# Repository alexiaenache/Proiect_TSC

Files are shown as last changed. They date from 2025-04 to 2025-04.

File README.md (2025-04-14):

# 📖 OpenBook – E-Reader cu ESP32-C6

**-TSC-**  
Alexia-Ioana Enache – 331CA

---

## 🧠 Arhitectură generală

Sistemul reprezintă un cititor digital inteligent, construit în jurul microcontrollerului **ESP32-C6**, optimizat pentru consum redus și interacțiune minimă din partea utilizatorului, având ca scop principal afișarea eficientă de conținut pe un ecran E-Ink.

---

## 🧩 Componente principale și funcționalitate

### 1. ESP32-C6 – Unitatea centrală de control
- **Funcție:** Coordonează toate componentele, gestionează afișajul și comunicația.
- **Caracteristici cheie:**
  - Procesor RISC-V performant.
  - Suport Wi-Fi 6 (802.11ax) pentru actualizări sau funcționalitate în rețea.
  - Moduri avansate de economisire a energiei (deep sleep, modem sleep).

---

### 2. Afișaj E-Ink
- **Tip:** Ecran monocrom (ex. 2.9"), optimizat pentru citire.
- **Control:** Prin interfață SPI, cu linii dedicate de comandă (CS, DC, RST, BUSY).
- **Beneficii:** Consum de curent extrem de redus între refresh-uri – ideal pentru aplicații de tip e-paper.

---

### 3. Senzor de mediu – BME688
- **Scop:** Monitorizare temperatură, umiditate, presiune și calitatea aerului.
- **Conectivitate:** I2C (implicit) sau SPI (alternativ).
- **Consum:** µA în stand-by, câțiva mA în funcționare activă.

---

### 4. Ceas în timp real – DS3231
- **Funcționalitate:** Menține ora exactă, ideal pentru time-stamping sau notificări programate.
- **Interfață:** I2C + pin de alarmă (INT/SQW).
- **Consum:** Sub 2 µA în menținerea ceasului pe baterie.

---

### 5. Memorie SPI – W25Q512 (64Mbit NOR Flash)
- **Rol:** Depozitare pentru fișiere, cărți, date configurabile.
- **Protocol:** SPI, suportând frecvențe mari pentru transfer rapid.
- **Eficiență energetică:** Consumă doar în timpul operațiunilor active.

---

### 6. Sistem de alimentare
- **USB-C:** Intrare de 5V pentru alimentare și comunicație.
- **Încărcare baterie:** MCP73831 controlează încărcarea Li-Po, cu curent reglat prin rezistor (ex. 500mA).
- **Conversie tensiune:**
  - **LDO / DC-DC:** Reglează 3.7V de la baterie la 3.3V pentru întreaga platformă.
  - Opțional: step-up DC-DC pentru a obține 5V dacă e necesar.

---

### 7. Control fizic – Butoane SMD
- 3 butoane dedicate: Boot, Reset și Funcțional.
- Legate la GPIO-uri configurate cu pull-up/pull-down.
- Logica de debounce poate fi software sau hardware.

---

### 8. Alte funcționalități
- Protecții ESD aplicate pe liniile critice: USB, SPI, I2C, alimentare.
- **Test Pads**: Acces facil la semnale importante (MISO, MOSI, SCK, RX, TX, GND, 3V3) pentru depanare sau programare externă.

---

## 🛠️ Considerații hardware (PCB Design)

### Rutare & alimentare:
- **Trasee de putere:** Minim 0.3 mm pentru 3V3, 5V, VBAT.
- **Linii de semnal:** Minim 0.15 mm pentru SPI, I2C, UART etc.
- **Grosime PCB:** Ideal < 1 mm pentru carcase compacte.

### Decuplare & stabilitate:
- Condensatoare **100nF** (0402) pentru fiecare pin VCC.
- Condensatoare **4.7 µF - 10 µF** pentru stabilizarea LDO și surse locale.

### Antenă ESP32-C6:
- Zona antenei trebuie eliberată de cupru (decupaj în GND + semnale), conform datasheetului Espressif.

### DRC/ ERC:
- Verificări obligatorii:
  - Unghiuri ≤ 45°.
  - Planuri GND corect cusute cu via stitching.
  - Clearance și distanțe respectate conform producătorului.

### Layout:
- Componente doar pe **Top Layer** (SMD).
- USB-C și butoanele poziționate ergonomic și accesibil.

### Test Pad-uri:
- Expunere pentru debug, programare și validare semnale: 3V3, GND, RX, TX, SPI.

---
## 📐 Diagrama bloc

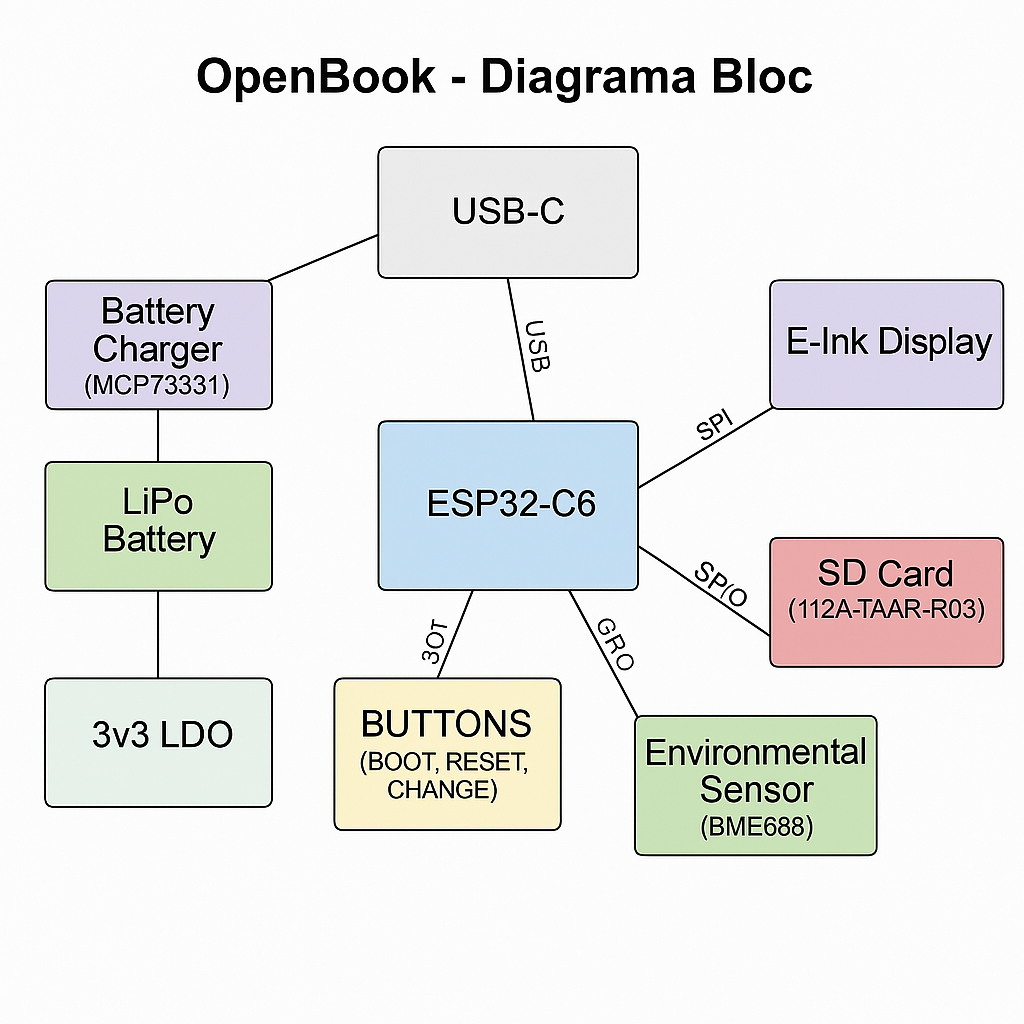
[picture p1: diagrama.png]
Diagrama Bloc


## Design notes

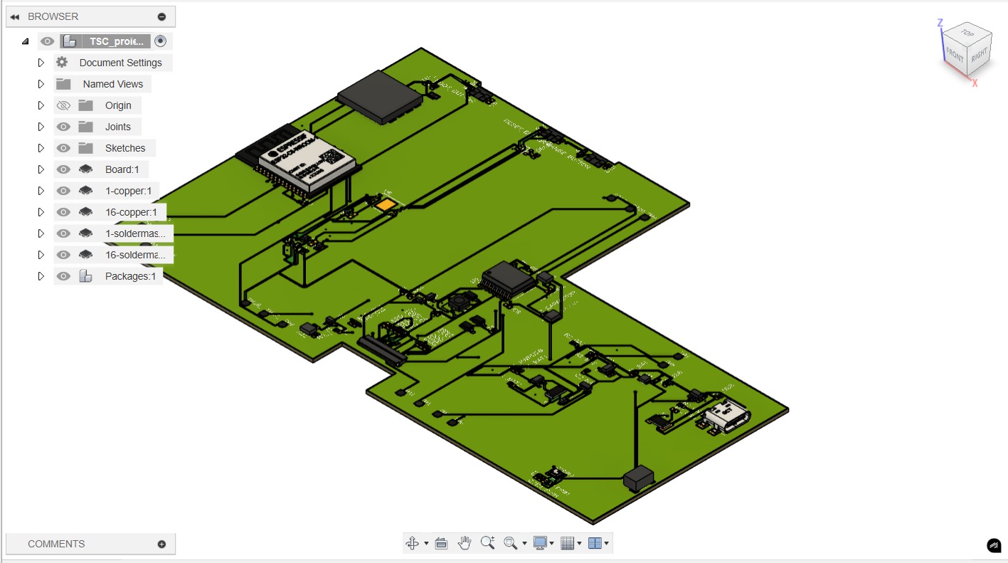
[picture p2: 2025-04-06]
Images/placa.jpeg

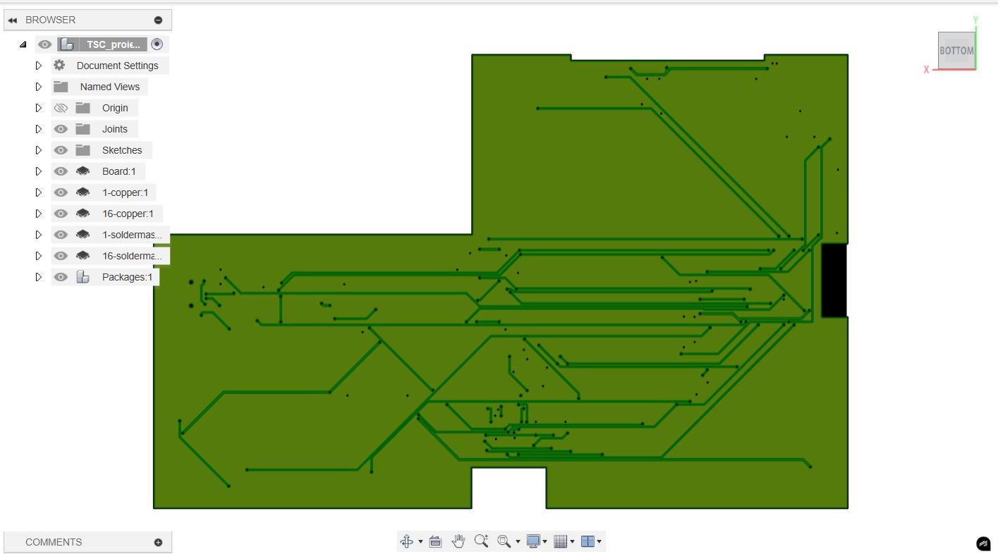
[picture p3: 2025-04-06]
Images/placa2.jpeg

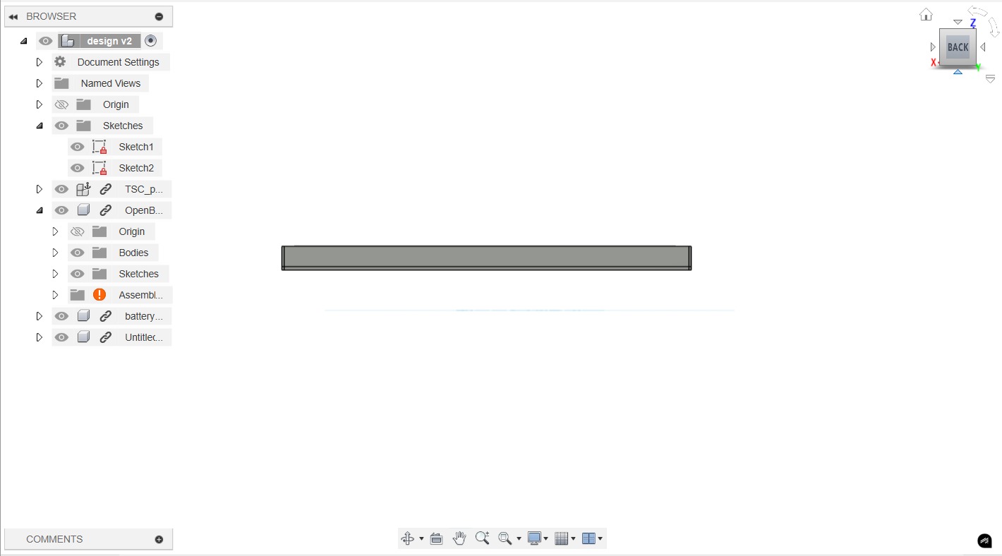
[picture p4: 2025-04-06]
Images/image.jpeg

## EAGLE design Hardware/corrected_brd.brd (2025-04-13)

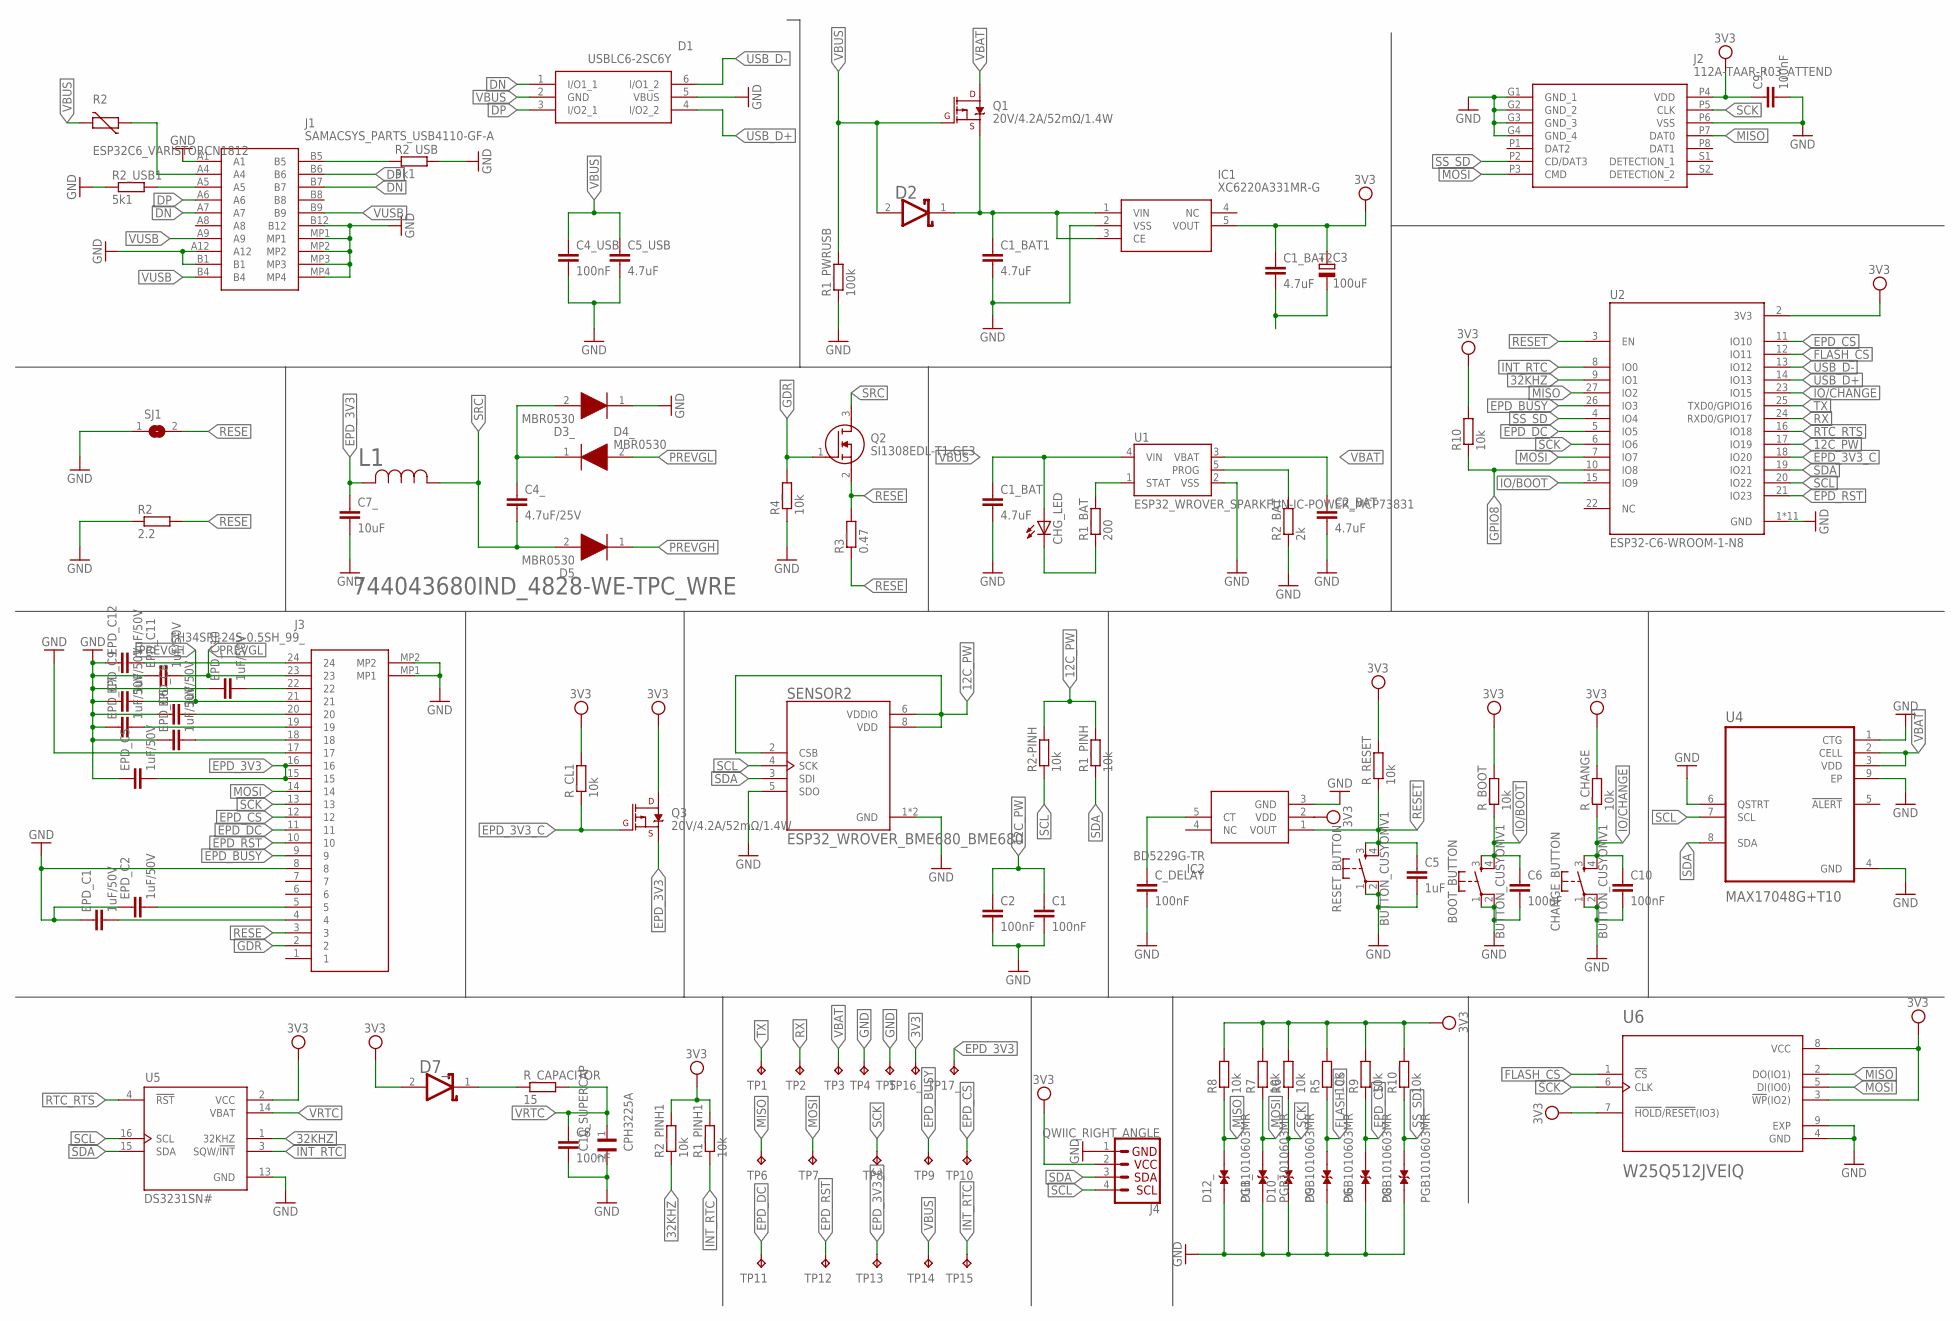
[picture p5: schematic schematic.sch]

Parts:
BOOT_BUTTON: BUTTON_CUSYOMV1; MYBUTTON
C1, C2, C4_USB, C8: 100nF; EAGLE-LTSPICE_C0402
C1_BAT, C1_BAT1, C1_BAT2, C2_BAT, C5_USB: 4.7uF; EAGLE-LTSPICE_C0402
C3: 100uF; RCL_CT3528
C4_: 4.7uF/25V; EAGLE-LTSPICE_C0402
C5: 1uF; EAGLE-LTSPICE_C0402
C6, C9_, C10: 100nF; ESP32_WROVER_EAGLE-LTSPICE_C0402
C7_: 10uF; EAGLE-LTSPICE_C0402
C10_SUPERCAP: CPH3225A; CAPCP3225X100N
CHANGE_BUTTON: BUTTON_CUSYOMV1; MYBUTTON
CHG_LED: ADAFRUIT_LEDCHIP-LED0603; ADAFRUIT_CHIP-LED0603
C_DELAY: 100nF; EAGLE-LTSPICE_C0402
D1: USBLC6-2SC6Y; SOT95P280X145-6N
D2, D7_: ESP32_WROVER_AVX---SD0805S020S1R0_AVX_SD0805S020S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; ESP32_WROVER_AVX---SD0805S020S1R0_AVX_SD0805S020S1R0_0
D3_, D4_, D5: MBR0530; SOD3716X135N
D6, D8, D9, D10_, D11_, D12_: PGB1010603MR; DIOC1608X36N
EPD_C1, EPD_C2, EPD_C5, EPD_C6, EPD_C7, EPD_C8, EPD_C9, EPD_C10, EPD_C11, EPD_C12: 1uF/50V; EAGLE-LTSPICE_C0402
IC1: XC6220A331MR-G; SOT95P280X120-5N
IC2: BD5229G-TR; SOT95P280X125-5N
J1: SAMACSYS_PARTS_USB4110-GF-A; SAMACSYS_PARTS_USB4110GFA
J2: 112A-TAAR-R03_ATTEND; 112ATAARR03ATTEND
J3: FH34SRJ-24S-0.5SH_99_; FH34SRJ24S05SH99
J4: QWIIC_RIGHT_ANGLE; JST04_1MM_RA
L1: 744043680IND_4828-WE-TPC_WRE; IND_4828-WE-TPC_WRE
Q1, Q3: 20V/4.2A/52mΩ/1.4W; ESP32_WROVER_SPARKFUN-DISCRETESEMI_SOT23-3
Q2: SI1308EDL-T1-GE3; SOT65P210X110-3N
R1_BAT: 200; ESP32_WROVER_EAGLE-LTSPICE_R0402
R1_PINH, R1_PINH1, R2-PINH, R2_PINH1, R4_, R5, R6, R7, R8, R9, R10, R10_: 10k; ESP32_WROVER_EAGLE-LTSPICE_R0402
R1_PWRUSB: 100k; ESP32_WROVER_EAGLE-LTSPICE_R0402
R2: ESP32C6_VARISTORCN1812; ESP32C6_VARISTOR_CT/CN1812
R2_: 2.2; ESP32_WROVER_EAGLE-LTSPICE_R0402
R2_BAT: 2k; ESP32_WROVER_EAGLE-LTSPICE_R0402
R2_USB, R2_USB1: 5k1; ESP32_WROVER_EAGLE-LTSPICE_R0402
R3_: 0.47; ESP32_WROVER_EAGLE-LTSPICE_R0402
RESET_BUTTON: BUTTON_CUSYOMV1; MYBUTTON
R_BOOT: 10k; ESP32_WROVER_EAGLE-LTSPICE_R0402
R_CAPACITOR: 15; ESP32_WROVER_EAGLE-LTSPICE_R0402
R_CHANGE: 10k; ESP32_WROVER_EAGLE-LTSPICE_R0402
R_CL1: 10k; ESP32_WROVER_EAGLE-LTSPICE_R0402
R_RESET: 10k; ESP32_WROVER_EAGLE-LTSPICE_R0402
SENSOR2: ESP32_WROVER_BME680_BME680; ESP32_WROVER_BME680_PSON80P300X300X100-8N
SJ1: SJ
TP1, TP2, TP3, TP4, TP5, TP6, TP7, TP8, TP9, TP10, TP11, TP12, TP13, TP14, TP15, TP16_, TP17_: TPTP20R; TP20R
U1: ESP32_WROVER_SPARKFUN-IC-POWER_MCP73831; ESP32_WROVER_SPARKFUN-IC-POWER_SOT23-5
U2: ESP32-C6-WROOM-1-N8; XCVR_ESP32-C6-WROOM-1-N8
U4: MAX17048G+T10; SON50P200X200X80-9N
U5: DS3231SN#; SOIC127P1032X265-16N
U6: W25Q512JVEIQ; SON127P600X800X80-9N

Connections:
3V3: C1_BAT2.1, C3.+, C9_.1, D7_.2 (ANODE), IC1.5 (VOUT), IC2.2 (VDD), J2.P4 (VDD), J4.2, Q3.3 (D), R1_PINH1.2, R2_PINH1.2, R5.2, R6.2, R7.2, R8.2, R9.2, R10.2, R10_.2, R_BOOT.2, R_CHANGE.2, R_CL1.2, R_RESET.2, TP16_.TP, U2.2 (3V3), U5.2 (VCC), U6.3 (!WP!(IO2)), U6.7 (!HOLD!/!RESET!(IO3)), U6.8 (VCC)
12C_PW: C1.1, C2.1, R1_PINH.2, R2-PINH.2, SENSOR2.2 (CSB), SENSOR2.6 (VDDIO), SENSOR2.8 (VDD), U2.17 (IO19)
32KHZ: R2_PINH1.1, U2.9 (IO1), U5.1 (32KHZ)
DN: D1.1 (I/O1_1), J1.A7, J1.B7
DP: D1.3 (I/O2_1), J1.A6, J1.B6
EPD_3V3: C7_.1, EPD_C5.2, J3.15, J3.16, L1.2, Q3.2 (S), TP17_.TP
EPD_3V3_C: Q3.1 (G), R_CL1.1, TP13.TP, U2.18 (IO20)
EPD_BUSY: J3.9, TP9.TP, U2.26 (IO3)
EPD_CS: D6.2, J3.12, R9.1, TP10.TP, U2.11 (IO10)
EPD_DC: J3.11, TP11.TP, U2.5 (IO5)
EPD_RST: J3.10, TP12.TP, U2.21 (IO23)
FLASH_CS: D9.2, R5.1, U2.12 (IO11), U6.1 (!CS)
GDR: J3.2, Q2.1 (G), R4_.2
GND: BOOT_BUTTON.1, BOOT_BUTTON.2, C1.2, C1_BAT.2, C1_BAT1.2, C2.2, C2_BAT.2, C4_USB.2, C5.2, C5_USB.2, C6.2, C7_.2, C8.2, C9_.2, C10.2, C10_SUPERCAP.2, CHANGE_BUTTON.1, CHANGE_BUTTON.2, C_DELAY.2, D1.5 (VBUS), D3_.1 (K), D6.1, D8.1, D9.1, D10_.1, D11_.1, D12_.1, EPD_C1.1, EPD_C2.1, EPD_C5.1, EPD_C6.1, EPD_C7.1, EPD_C8.1, EPD_C9.1, EPD_C10.1, EPD_C11.1, EPD_C12.1, IC1.2 (VSS), IC2.3 (GND), J1.A1, J1.A12, J1.B1, J1.B12, J1.MP1, J1.MP2, J1.MP3, J1.MP4, J2.G1 (GND_1), J2.G2 (GND_2), J2.G3 (GND_3), J2.G4 (GND_4), J2.P6 (VSS), J3.8, J3.17, J3.MP1, J3.MP2, J4.1, R1_PWRUSB.1, R2_.1, R2_BAT.1, R2_USB.2, R2_USB1.1, R4_.1, RESET_BUTTON.1, RESET_BUTTON.2, SENSOR2.1 (GND), SENSOR2.5 (SDO), SENSOR2.7 (GND), SJ1.1, TP4.TP, TP5.TP, U1.2 (VSS), U2.1 (GND), U2.28 (GND), U2.29_1 (GND), U2.29_2 (GND), U2.29_3 (GND), U2.29_4 (GND), U2.29_5 (GND), U2.29_6 (GND), U2.29_7 (GND), U2.29_8 (GND), U2.29_9 (GND), U4.1 (CTG), U4.4 (GND), U4.6 (QSTRT), U4.9 (EP), U5.13 (GND), U6.4 (GND), U6.9 (EXP)
GPIO8: R10.1, U2.10 (IO8)
INT_RTC: R1_PINH1.1, TP15.TP, U2.8 (IO0), U5.3 (SQW/!INT)
IO/BOOT: BOOT_BUTTON.3, BOOT_BUTTON.4, C6.1, R_BOOT.1, U2.15 (IO9)
IO/CHANGE: C10.1, CHANGE_BUTTON.3, CHANGE_BUTTON.4, R_CHANGE.1, U2.23 (IO15)
MISO: D12_.2, J2.P7 (DAT0), R8.1, TP6.TP, U2.27 (IO2), U6.2 (DO(IO1))
MOSI: D11_.2, J2.P3 (CMD), J3.14, R7.1, TP7.TP, U2.7 (IO7), U6.5 (DI(IO0))
unnamed: J1.A4, R2.1
unnamed: J1.A5, R2_USB1.2
unnamed: J1.B5, R2_USB.1
unnamed: C1_BAT1.1, D2.1 (CATHODE), IC1.1 (VIN), IC1.3 (CE), Q1.2 (S)
unnamed: C4_.1, D3_.2 (A), D4_.1 (K)
unnamed: C1_BAT2.2, C3.-
unnamed: EPD_C12.2, J3.24
unnamed: EPD_C1.2, J3.4
unnamed: C_DELAY.1, IC2.5 (CT)
unnamed: R2_BAT.2, U1.5 (PROG)
unnamed: EPD_C2.2, J3.5
unnamed: EPD_C10.2, J3.22
unnamed: D7_.1 (CATHODE), R_CAPACITOR.1
unnamed: R1_BAT.2, U1.1 (STAT)
unnamed: CHG_LED.C, R1_BAT.1
unnamed: EPD_C8.2, J3.20
unnamed: EPD_C7.2, J3.19
unnamed: EPD_C6.2, J3.18
PREVGH: D5.1 (K), EPD_C9.2, J3.21
PREVGL: D4_.2 (A), EPD_C11.2, J3.23
RESE: J3.3, Q2.2 (S), R2_.2, R3_.1, R3_.2, SJ1.2
RESET: C5.1, IC2.1 (VOUT), RESET_BUTTON.3, RESET_BUTTON.4, R_RESET.1, U2.3 (EN)
RTC_RTS: U2.16 (IO18), U5.4 (!RST)
RX: TP2.TP, U2.24 (RXD0/GPIO17)
SCK: D10_.2, J2.P5 (CLK), J3.13, R6.1, TP8.TP, U2.6 (IO6), U6.6 (CLK)
SCL: J4.4, R2-PINH.1, SENSOR2.4 (SCK), U2.20 (IO22), U4.7 (SCL), U5.16 (SCL)
SDA: J4.3, R1_PINH.1, SENSOR2.3 (SDI), U2.19 (IO21), U4.8 (SDA), U5.15 (SDA)
SRC: C4_.2, D5.2 (A), L1.1, Q2.3 (D)
SS_SD: D8.2, J2.P2 (CD/DAT3), R10_.1, U2.4 (IO4)
TX: TP1.TP, U2.25 (TXD0/GPIO16)
USB_D+: D1.4 (I/O2_2), U2.14 (IO13)
USB_D-: D1.6 (I/O1_2), U2.13 (IO12)
VBAT: C2_BAT.1, Q1.3 (D), TP3.TP, U1.3 (VBAT), U4.2 (CELL), U4.3 (VDD)
VBUS: C1_BAT.1, C4_USB.1, C5_USB.1, CHG_LED.A, D1.2 (GND), D2.2 (ANODE), Q1.1 (G), R1_PWRUSB.2, R2.2, TP14.TP, U1.4 (VIN)
VRTC: C8.1, C10_SUPERCAP.1, R_CAPACITOR.2, U5.14 (VBAT)
VUSB: J1.A9, J1.B4, J1.B9

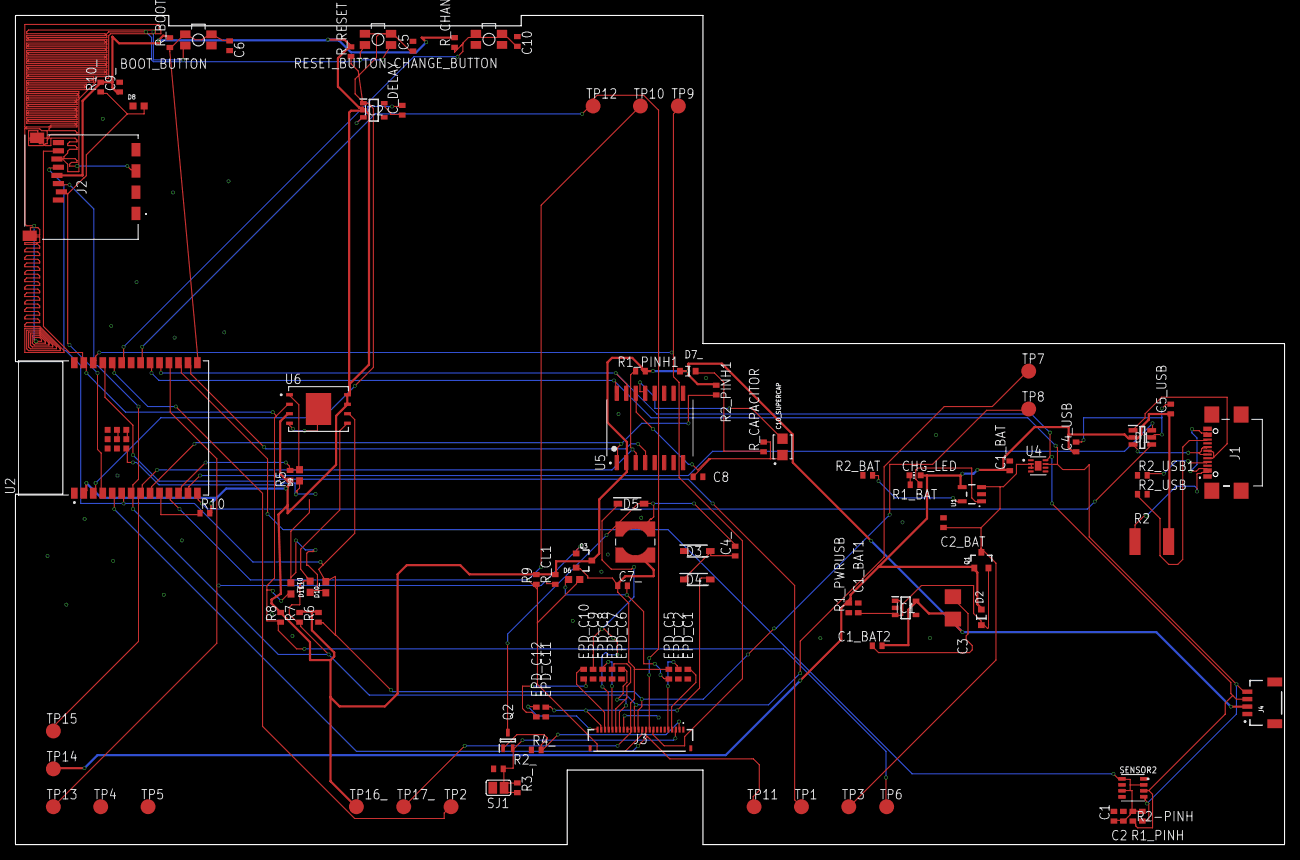
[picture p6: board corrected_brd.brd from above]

Board: 2 copper layers, 170.2 x 111.2 mm, 103 parts (0 on the bottom side), 56 nets.

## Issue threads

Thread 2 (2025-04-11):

Probleme de etichetare și elemente lipsă în schematic

vasilicadantis, 2025-04-11:
**1. USB C connector & ESD protection:**

- [x] R2 trebuie redenumit in _PFMF.050.1_ si trebuie legat si la _VUSB_(eticheta)

**2. LDO Voltage Regulator:**

- [x]  _C1_BAT2_ si _C3_ nu sunt legate la _GND_

**3.Display Type Selector**

- [x]  Etichetele nu sunt _RESE_ , sunt _RESE_'( sunt de 2 feluri, stiu :)) )

**4.E-Paper Drive Circuit**

- [x]  Aici era _RESE_' nu _RESE_ in schematicul dat drept model.

**5.ESP32 C6**

- [x]  Rezistenta denumita gresit ( _R1-R10_) ( difera de model)

- [x]  ai un label _RTC_RTS_ si trebuia _RTC_RST_ ( stiu, nu conteaza foarte mult dar am zis sa iti spun)

**6.Environmental Sensor BME688**

- [x] Label _12C_PW_ in loc de  _I2C_PW_ ( dar denumindu-le peste tot asa, nu te incurca)

In general, este ok. mici scapari dar in principiu este bine.

Closed 2025-04-14.

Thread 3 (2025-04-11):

Schema PCB 2D layout - Grosime Placa si Dimensiuni

vasilicadantis, 2025-04-11:
- [x] **Pentru  a intra  în cutie, _PCB-ul trebuie să aibă 1mm grosime._**

 _Grosimea standard în Fusion360 este 1.6mm_, deci va trebui sa modifici  pentru a arata ok in 3D (**HINT** : design - layers - layes stack - edit material properties)

- [x] **Dimensiunile placii** sunt trasate cu _layerul top_. (**HINT:** Trebuie schimbate in document)

Closed 2025-04-13.

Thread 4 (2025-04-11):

Amplasament componente PCB

vasilicadantis, 2025-04-11:
**1. BUTOANE**
- Acestea trebuie _sa iasa usor in exterior_ si sa fie amplasate perfect pe conturul placii ( adica sa arate mai realist putin )

**2. J2 , J1, J4**
- J2: De asemenea trebuie sa fie putin in _exterior_ ( poti obseva mai exact cum in fisierul oferit pentru proiect)
- J1: Sa fie putin in _exterior_ ( este conectorul USB si normal, trebuie sa ia "contact" cu exteriorul). Trebuie sa fie si centrat dupa masuratori astfel incat sa intre perfect in carcasa la 3D
- J4: Cat mai aproape de _exterior_ ( _atentie,_ acesta nu trebuie iesit de pe placuta. doar cat mai pe margine)

Closed 2025-04-13.

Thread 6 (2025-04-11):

Rutare

vasilicadantis, 2025-04-11:
- [x]  Apar unele **vias-uri** " in aer"

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

- [x]  Ai **unghiuri drepte** la rutare

- [x] Am obsevat anumite **suprapuneri la rutele de GND** (dreapta sus)

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

- [x] Am observat  la R7 un **wire in aer**, nu se ducea nicaieri

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

- [x]  **Traseele de putere** nu sunt toate de dimensiune 0.3mm. (**HINT**: toate traseele de putere sunt : 3V3, VBAT, VBUS, VUSB, VRT, I2C_PW, EDC_3V3, EDC_3V3_C)

Closed 2025-04-13.

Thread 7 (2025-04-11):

Via Stitching

vasilicadantis, 2025-04-11:
- [x]  Lipseste **Via Stitching** între cele două planuri de masă _(trebuie amplasat _în special în preajma modulului ESP32)_._

**HINT** : Route - Via Stitching

Closed 2025-04-13.

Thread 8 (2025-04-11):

Componente 3D

vasilicadantis, 2025-04-11:
- [x]  Multe **componente lipsesc**. (ex : butoane)

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

- [x] **Componenete orientate gresit** din punct de vedere al pinilor (**HINT:** in momentul in care incarci obiectul 3D, il poti roti/misca si totul va fi in ordine)

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

- [x] **Componente prea mici** (**HINT:** trebuie scalate conform placii)

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

- [x]  **HINT:** Pentru **TP-uri** poti sa faci tu un element 3D (ex: un cilindru mic)

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

Closed 2025-04-13.

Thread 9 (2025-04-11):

3D Design

vasilicadantis, 2025-04-11:
- [x] **Nu exista o corelare intre amplasarea: Placa + Baterie cu Carcasa + Display.**

**ex:** Locul unde sunt butoanele amplasate pe placa nu corespunde cu locul unde sunt amplasate pe carcasa.
**HINT:** Pentru a corecta problema poti roti cu fata in jos placa si bateria.

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

- [x]  Din cauza  **amplasarii gresite** a **USB-ului** in schema PCB, acesta nu se potriveste perfect in carcasa( nu este centrat si se afla la distanta fata de aceasta)

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

- [x]  ****Display-ul nu se aseaza perfect**:**

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

Closed 2025-04-13.

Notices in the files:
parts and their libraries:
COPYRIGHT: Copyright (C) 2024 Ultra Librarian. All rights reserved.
